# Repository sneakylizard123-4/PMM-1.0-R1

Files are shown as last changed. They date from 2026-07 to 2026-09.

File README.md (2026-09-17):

# PMM-1.0-R1 (Power Management Module)

A USB-C battery management module with charging, fuel gauging, and a switched 5V output.

## Custom Features

- BQ25895 2A buck charger with I2C control
- BQ27441-G1 fuel gauge
- TPS61089 boost converter for 5V output
- TPS22917 load
- TLV75733 3.3V LDO
- STM32C031C4T6 MCU
- 4-layer PCB, 50x30mm

## PCB Design

this board is designed to fit on a breadboard without much hassle
it is a 4-layer pcb with an inner ground layer

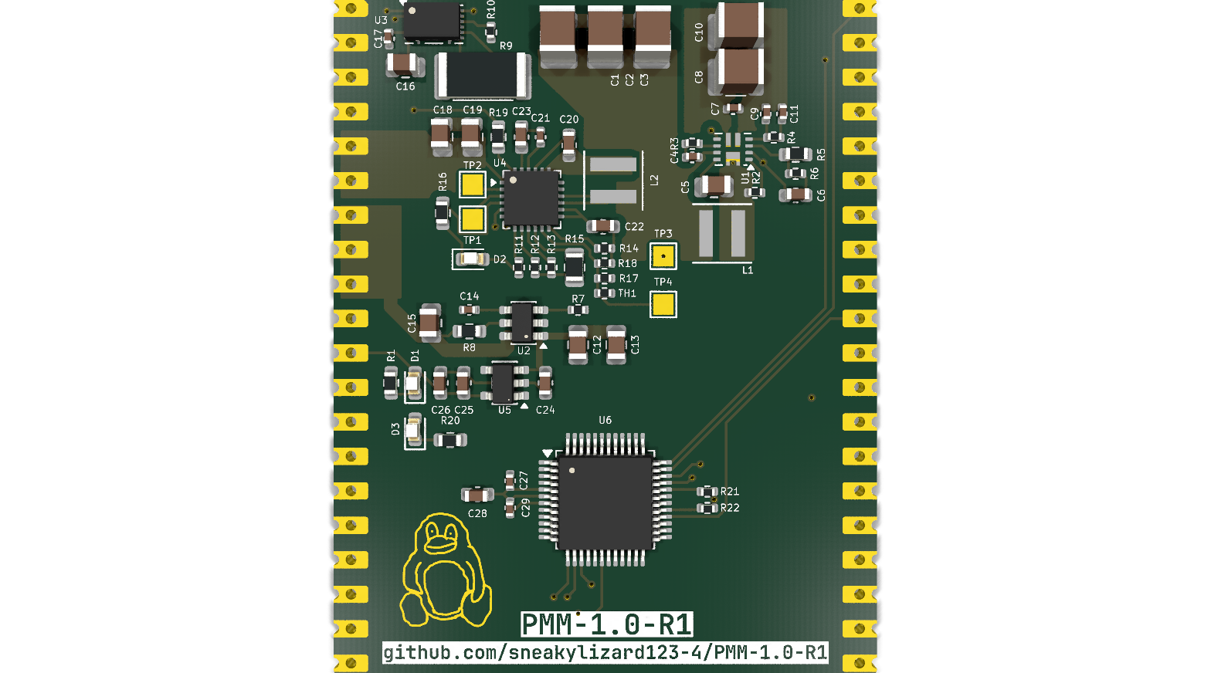
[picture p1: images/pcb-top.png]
PCB Top

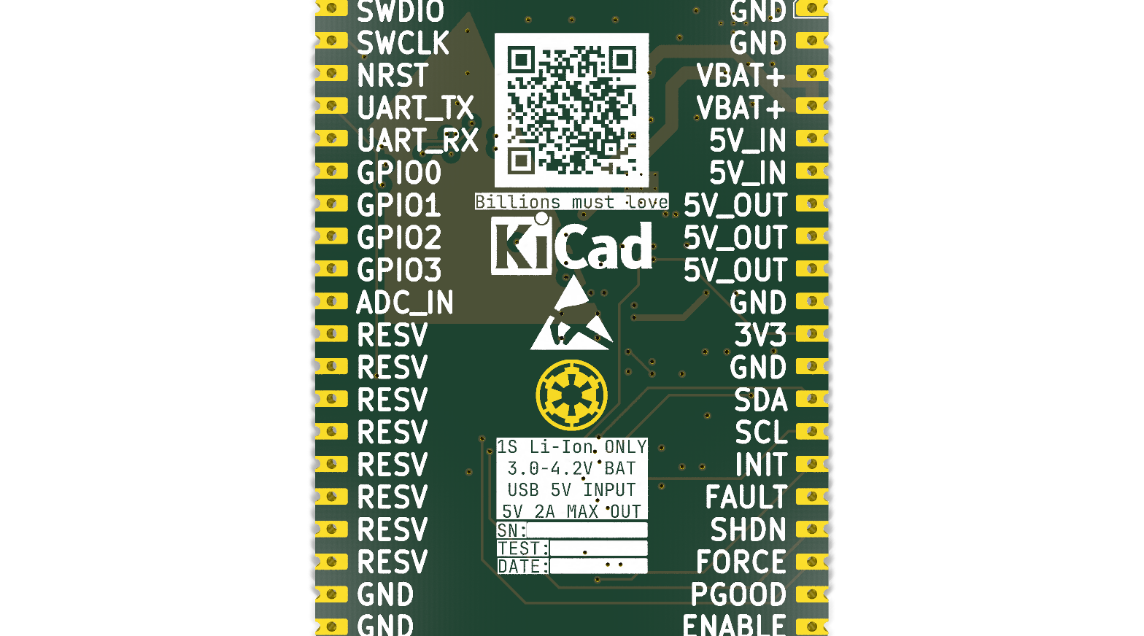
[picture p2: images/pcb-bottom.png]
PCB Bottom

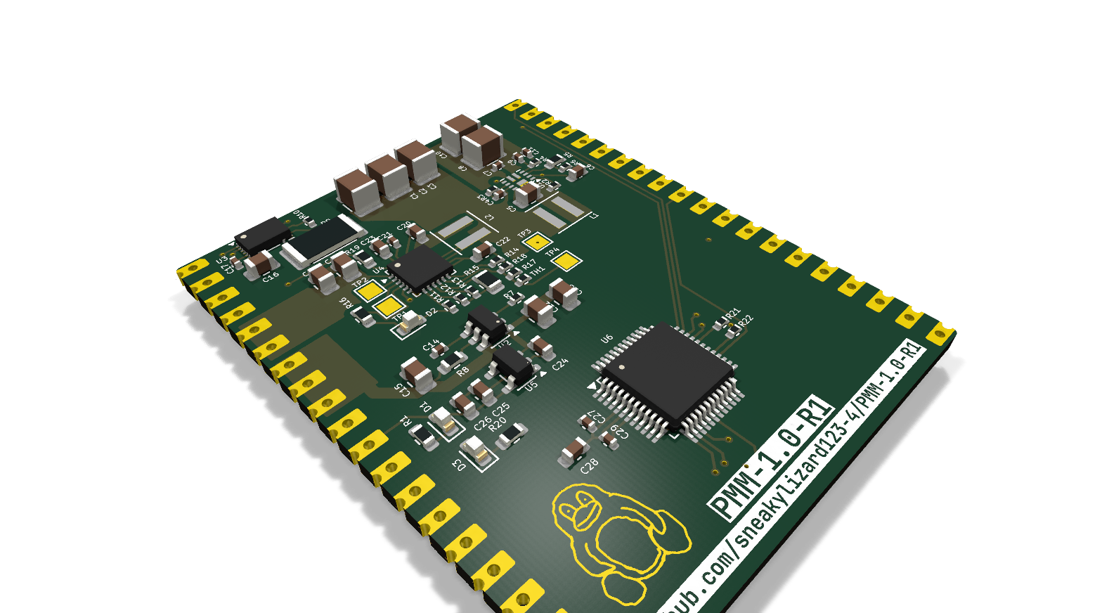
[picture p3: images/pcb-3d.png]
3D View


## Firmware

PlatformIO project using internal 48MHz oscillator (no crystal).

- I2C1 (PA9/PA10): BQ25895 charger at 0x6B, BQ27441 fuel gauge at 0x55
- USART2 (PA2/PA3): 115200 debug/status output
- ADC1 (PA8): VBUS monitoring
- GPIO: load switch (PA0), charger CE (PA4), LED (PA6), SHDN (PA11), FORCE_ON (PA12)

Flash with PlatformIO:

```
pio run -t upload
```

## BOM (Bill of Materials)

| Ref | Value | LCSC # | MPN | Manufacturer | Footprint | Qty | Unit $ | Ext $ | Link |
|-----|---|---|-----|---|---|-----|---|---|---|
| C1-C3,C8,C10 | 47uF 1210 16V X5R | C6783889 | 1210X476M160CT | Walsin | 1210 | 5 | 0.0900 | 0.4500 | [LCSC](https://www.lcsc.com/product-detail/C6783889.html) |
| C4,C7,C14,C27,C29 | 100nF 0402 25V X7R | C56392 | 0402B104K250NT | FH(Guangdong Fenghua) | 0402 | 5 | 0.0115 | 0.0575 | [LCSC](https://www.lcsc.com/product-detail/C56392.html) |
| C5 | 100nF 0805 50V X7R | C83055 | 0805B104K500CT | Walsin | 0805 | 1 | 0.0100 | 0.0100 | [LCSC](https://www.lcsc.com/product-detail/C83055.html) |
| C6,C22,C23,C28 | 10uF 0603 10V X5R | C19702 | CL10A106KP8NNNC | Samsung | 0603 | 4 | 0.0065 | 0.0260 | [LCSC](https://www.lcsc.com/product-detail/C19702.html) |
| C9 | 24pF 0402 C0G | C2242874 | C0402C240J4GACTU | KEMET | 0402 | 1 | 0.0100 | 0.0100 | [LCSC](https://www.lcsc.com/product-detail/C2242874.html) |
| C11 | 560pF 0402 C0G 50V | C3895255 | C0402C0G500-561FNP | Venkel | 0402 | 1 | 0.0313 | 0.0313 | [LCSC](https://www.lcsc.com/product-detail/C3895255.html) |
| C12,C19 | 100nF 0805 50V X7R | C83055 | 0805B104K500CT | Walsin | 0805 | 2 | 0.0100 | 0.0200 | [LCSC](https://www.lcsc.com/product-detail/C83055.html) |
| C13,C18 | 10uF 0805 10V X7R | C396720 | 0805B106K100CT | Walsin | 0805 | 2 | 0.0950 | 0.1900 | [LCSC](https://www.lcsc.com/product-detail/C396720.html) |
| C15 | 47uF 0805 10V X5R | C6119904 | CGA0805X5R476M100MT | HRE | 0805 | 1 | 0.1000 | 0.1000 | [LCSC](https://www.lcsc.com/product-detail/C6119904.html) |
| C16 | 1uF 0805 16V X7R | C2991444 | 0805B105K160CT-C | Walsin | 0805 | 1 | 0.0230 | 0.0230 | [LCSC](https://www.lcsc.com/product-detail/C2991444.html) |
| C17 | 0.47uF 0402 10V X5R | C47339 | CL05A474KP5NNNC | Samsung | 0402 | 1 | 0.0200 | 0.0200 | [LCSC](https://www.lcsc.com/product-detail/C47339.html) |
| C20 | 47nF 0603 25V X7R | C3881195 | C0603C473J3RAC7867 | KEMET | 0603 | 1 | 0.0100 | 0.0100 | [LCSC](https://www.lcsc.com/product-detail/C3881195.html) |
| C21 | 4.7uF 0402 6.3V X5R | C340648 | 0402X475M6R3CT | Walsin | 0402 | 1 | 0.0240 | 0.0240 | [LCSC](https://www.lcsc.com/product-detail/C340648.html) |
| C24,C25 | 1uF 0603 16V X7R | C106248 | CC0603KRX7R7BB105 | YAGEO | 0603 | 2 | 0.0310 | 0.0620 | [LCSC](https://www.lcsc.com/product-detail/C106248.html) |
| C26 | 100nF 0603 50V X7R | C14663 | CC0603KRX7R9BB104 | YAGEO | 0603 | 1 | 0.0100 | 0.0100 | [LCSC](https://www.lcsc.com/product-detail/C14663.html) |
| D1-D3 | LED 0603 emerald green | C7429914 | NCD0603G3 | NATIONSTAR | 0603 | 3 | 0.0080 | 0.0240 | [LCSC](https://www.lcsc.com/product-detail/C7429914.html) |
| L1 | 470nH shielded power inductor | C18221164 | XFL4015-471MEC | Coilcraft | SMD 4x4mm | 1 | 1.5000 | 1.5000 | [LCSC](https://www.lcsc.com/product-detail/C18221164.html) |
| L2 | 2.2uH shielded power inductor 8A | C122469 | XFL4020-222MEC | Coilcraft | SMD 4x4mm | 1 | 1.5000 | 1.5000 | [LCSC](https://www.lcsc.com/product-detail/C122469.html) |
| R1,R16,R19,R20 | 10k 0603 1% | C98220 | RC0603FR-0710KL | YAGEO | 0603 | 4 | 0.0100 | 0.0400 | [LCSC](https://www.lcsc.com/product-detail/C98220.html) |
| R2 | 309k 0402 1% | C171694 | RC0402FR-07309KL | YAGEO | 0402 | 1 | 0.0100 | 0.0100 | [LCSC](https://www.lcsc.com/product-detail/C171694.html) |
| R3 | 133k 0402 1% | C3015855 | SCR0402F133K | VO | 0402 | 1 | 0.0100 | 0.0100 | [LCSC](https://www.lcsc.com/product-detail/C3015855.html) |
| R4 | 28.7k 0402 1% | C185433 | RC0402FR-0728K7L | YAGEO | 0402 | 1 | 0.0100 | 0.0100 | [LCSC](https://www.lcsc.com/product-detail/C185433.html) |
| R5 | 240k 0603 1% | C137765 | RC0603FR-07240KL | YAGEO | 0603 | 1 | 0.0100 | 0.0100 | [LCSC](https://www.lcsc.com/product-detail/C137765.html) |
| R6 | 76.8k 0402 1% | C185396 | RC0402FR-0776K8L | YAGEO | 0402 | 1 | 0.0100 | 0.0100 | [LCSC](https://www.lcsc.com/product-detail/C185396.html) |
| R7 | 100k 0402 1% | C60491 | RC0402FR-07100KL | YAGEO | 0402 | 1 | 0.0060 | 0.0060 | [LCSC](https://www.lcsc.com/product-detail/C60491.html) |
| R8 | 100k 0603 1% | C14675 | RC0603FR-07100KL | YAGEO | 0603 | 1 | 0.0100 | 0.0100 | [LCSC](https://www.lcsc.com/product-detail/C14675.html) |
| R9 | 0.010 ohm 1% 2512 3W shunt | C520398 | LCSR2512FR010Q9L | RESI | 2512 | 1 | 0.1000 | 0.1000 | [LCSC](https://www.lcsc.com/product-detail/C520398.html) |
| R10-R14 | 10k 0402 1% | C60490 | RC0402FR-0710KL | YAGEO | 0402 | 5 | 0.0100 | 0.0500 | [LCSC](https://www.lcsc.com/product-detail/C60490.html) |
| R15 | 130 ohm 0805 1% | C273821 | RC0805FR-07130RL | YAGEO | 0805 | 1 | 0.0100 | 0.0100 | [LCSC](https://www.lcsc.com/product-detail/C273821.html) |
| R17 | 5.23k 0402 1% | C477746 | RC0402FR-075K23L | YAGEO | 0402 | 1 | 0.0100 | 0.0100 | [LCSC](https://www.lcsc.com/product-detail/C477746.html) |
| R18 | 30.1k 0402 1% | C138009 | RC0402FR-0730K1L | YAGEO | 0402 | 1 | 0.0100 | 0.0100 | [LCSC](https://www.lcsc.com/product-detail/C138009.html) |
| R21,R22 | 4.7k 0402 1% | C105871 | RC0402FR-074K7L | YAGEO | 0402 | 2 | 0.0100 | 0.0200 | [LCSC](https://www.lcsc.com/product-detail/C105871.html) |
| TH1 | 10k NTC thermistor 0402 | C77131 | NCP15XH103F03RC | muRata | 0402 | 1 | 0.0266 | 0.0266 | [LCSC](https://www.lcsc.com/product-detail/C77131.html) |
| U1 | TPS61089RNRR boost converter | C165129 | TPS61089RNRR | Texas Instruments | VQFN-11 | 1 | 0.5800 | 0.5800 | [LCSC](https://www.lcsc.com/product-detail/C165129.html) |
| U2 | TPS22917DBVR load switch | C2681320 | TPS22917DBVR | Texas Instruments | SOT-23-6 | 1 | 0.4600 | 0.4600 | [LCSC](https://www.lcsc.com/product-detail/C2681320.html) |
| U3 | BQ27441DRZR-G1B fuel gauge | C473374 | BQ27441DRZR-G1B | Texas Instruments | SON-12 | 1 | 2.7600 | 2.7600 | [LCSC](https://www.lcsc.com/product-detail/C473374.html) |
| U4 | BQ25895RTWR charger | C80200 | BQ25895RTWR | Texas Instruments | WQFN-24 | 1 | 2.1700 | 2.1700 | [LCSC](https://www.lcsc.com/product-detail/C80200.html) |
| U5 | TLV75733PDBVR 3.3V LDO | C485517 | TLV75733PDBVR | Texas Instruments | SOT-23-5 | 1 | 0.1950 | 0.1950 | [LCSC](https://www.lcsc.com/product-detail/C485517.html) |
| U6 | STM32C031C4T6 MCU | C5456207 | STM32C031C4T6 | STMicroelectronics | LQFP-48 | 1 | 1.6700 | 1.6700 | [LCSC](https://www.lcsc.com/product-detail/C5456207.html) |
| PCB | Bare PCB 50x30mm 4-layer | - | - | - | - | 1 | 2.5000 | 2.5000 | - |
| **Total** | - | - | - | - | - | **64** | - | **14.7354** | - |

Full BOM CSV: [BOM.csv](BOM.csv)

## Production

This board is designed for a standard 4-layer PCB fab:
- 4 layers
- HASL Lead Free
- 1.6mm board

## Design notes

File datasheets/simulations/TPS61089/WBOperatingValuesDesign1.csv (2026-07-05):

Name | Value | Category | Description
Phase Marg | 59.01 ° | System Information | Bode Plot Phase Margin
Cross Freq | 36.18 kHz | System Information | Bode plot crossover frequency
Low Freq Gain | 97.49 dB | System Information | Gain at 1Hz
Gain Marg | -13.31 dB | System Information | Bode Plot Gain Margin
Cin IRMS | 1.61 A | Capacitor | Input capacitor RMS ripple current
Cin Pd | 2.63 mW | Capacitor | Input capacitor power dissipation
Cout IRMS | 2.26 A | Capacitor | Output capacitor RMS ripple current
Cout Pd | 7.75 mW | Capacitor | Output capacitor power dissipation
Duty Cycle | 48.31% | System Information | Duty cycle
Efficiency | 93.7% | System Information | Steady state efficiency
Frequency | 496.71 kHz | System Information | Switching frequency
IC Tj | 53.04 °C | IC | IC junction temperature
ICThetaJA Effective | 39.2 °C/W | IC | Effective IC Junction-to-Ambient Thermal Resistance
L Ipp | 5.59 A | Inductor | Peak-to-peak inductor ripple current
L Pd | 71.05 mW | Inductor | Inductor power dissipation
IC Pd | 587.73 mW | IC | IC power dissipation
Pout | 10 W | System Information | Total output power
Iin Avg | 3.95 A | IC | Average input current
IC Ipk | 6.75 A | IC | Peak switch current in IC
Mode | BOOST CCM | System Information | PWM/PFM Mode
Vout p-p | 38.09 mV | System Information | Peak-to-peak output ripple voltage
Coutx Pd | 0 W | Capacitor | Output capacitor_x power loss
FootPrint | 144 mm² | System Information | Total Foot Print Area of BOM components
Vout Actual | 5 V | System Information | Vout Actual calculated based on selected voltage divider resistors
Vout Tolerance | 4.17% | System Information | Vout Tolerance based on IC Tolerance (no load) and voltage divider resistors if applicable
Vin | 2.7 V | System Information | Vin operating point
Iout | 2 A | System Information | Iout operating point
Cin Pd | 2.63 mW | Power | Input capacitor power dissipation
Cout Pd | 7.75 mW | Power | Output capacitor power dissipation
L Pd | 71.05 mW | Power | Inductor power dissipation
IC Pd | 587.73 mW | Power | IC power dissipation
Coutx Pd | 0 W | Power | Output capacitor_x power loss
Total BOM | $3.28 | System Information | Total BOM Cost
Total Pd | 669.29 mW | Power | Total Power Dissipation
BOM Count | 17 | System Information | Total Design BOM count

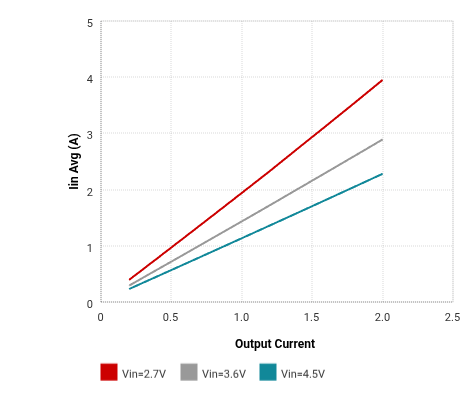
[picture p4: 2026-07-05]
datasheets/simulations/TPS61089/amCharts (8).png

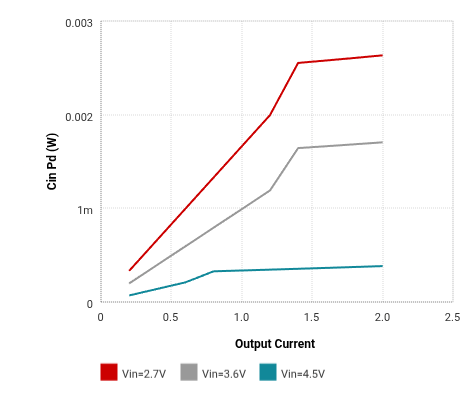
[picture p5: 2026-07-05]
datasheets/simulations/TPS61089/amCharts (5).png

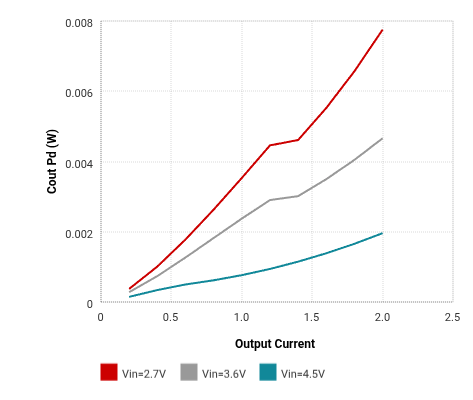
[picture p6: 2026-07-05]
datasheets/simulations/TPS61089/amCharts (12).png

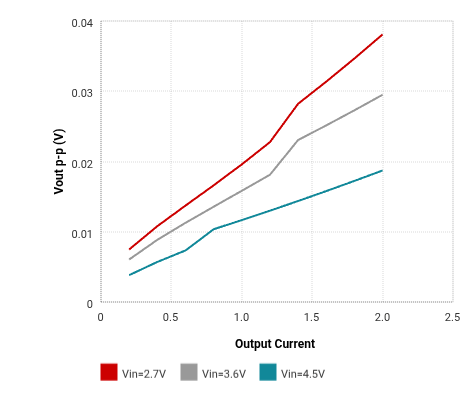
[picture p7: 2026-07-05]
datasheets/simulations/TPS61089/amCharts (1).png

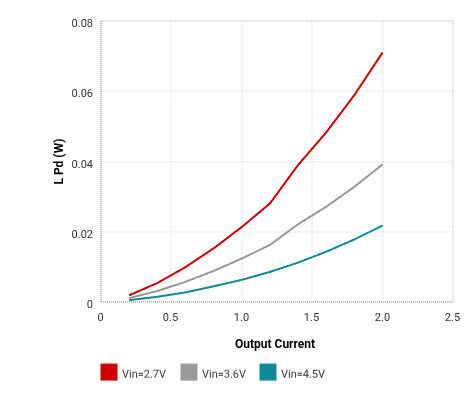
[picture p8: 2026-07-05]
datasheets/simulations/TPS61089/amCharts (15).png

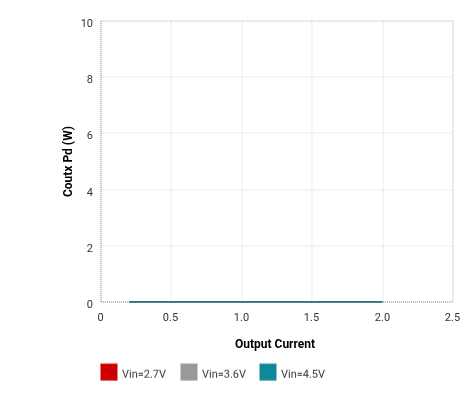
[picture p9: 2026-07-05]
datasheets/simulations/TPS61089/amCharts (7).png

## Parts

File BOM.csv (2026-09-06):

Ref | Value | Footprint | Qty | Manufacturer | MPN | LCSC Part | LCSC Link | Unit Price (USD) | Qty x Price
C1-C3,C8,C10 | 47uF 1210 16V X5R | Capacitor_SMD:C_1210_3225Metric | 5 | Walsin | 1210X476M160CT | C6783889 | https://www.lcsc.com/product-detail/C6783889.html | 0.0900 | 0.4500
C4,C7,C14,C27,C29 | 100nF 0402 25V X7R | Capacitor_SMD:C_0402_1005Metric | 5 | FH(Guangdong Fenghua) | 0402B104K250NT | C56392 | https://www.lcsc.com/product-detail/C56392.html | 0.0115 | 0.0575
C5 | 100nF 0805 50V X7R | Capacitor_SMD:C_0805_2012Metric | 1 | Walsin | 0805B104K500CT | C83055 | https://www.lcsc.com/product-detail/C83055.html | 0.0100 | 0.0100
C6,C22,C23,C28 | 10uF 0603 10V X5R | Capacitor_SMD:C_0603_1608Metric | 4 | Samsung | CL10A106KP8NNNC | C19702 | https://www.lcsc.com/product-detail/C19702.html | 0.0065 | 0.0260
C9 | 24pF 0402 C0G | Capacitor_SMD:C_0402_1005Metric | 1 | KEMET | C0402C240J4GACTU | C2242874 | https://www.lcsc.com/product-detail/C2242874.html | 0.0100 | 0.0100
C11 | 560pF 0402 C0G 50V | Capacitor_SMD:C_0402_1005Metric | 1 | Venkel | C0402C0G500-561FNP | C3895255 | https://www.lcsc.com/product-detail/C3895255.html | 0.0313 | 0.0313
C12,C19 | 100nF 0805 50V X7R | Capacitor_SMD:C_0805_2012Metric | 2 | Walsin | 0805B104K500CT | C83055 | https://www.lcsc.com/product-detail/C83055.html | 0.0100 | 0.0200
C13,C18 | 10uF 0805 10V X7R | Capacitor_SMD:C_0805_2012Metric | 2 | Walsin | 0805B106K100CT | C396720 | https://www.lcsc.com/product-detail/C396720.html | 0.0950 | 0.1900
C15 | 47uF 0805 10V X5R | Capacitor_SMD:C_0805_2012Metric | 1 | HRE | CGA0805X5R476M100MT | C6119904 | https://www.lcsc.com/product-detail/C6119904.html | 0.1000 | 0.1000
C16 | 1uF 0805 16V X7R | Capacitor_SMD:C_0805_2012Metric | 1 | Walsin | 0805B105K160CT-C | C2991444 | https://www.lcsc.com/product-detail/C2991444.html | 0.0230 | 0.0230
C17 | 0.47uF 0402 10V X5R | Capacitor_SMD:C_0402_1005Metric | 1 | Samsung | CL05A474KP5NNNC | C47339 | https://www.lcsc.com/product-detail/C47339.html | 0.0200 | 0.0200
C20 | 47nF 0603 25V X7R | Capacitor_SMD:C_0603_1608Metric | 1 | KEMET | C0603C473J3RAC7867 | C3881195 | https://www.lcsc.com/product-detail/C3881195.html | 0.0100 | 0.0100
C21 | 4.7uF 0402 6.3V X5R | Capacitor_SMD:C_0402_1005Metric | 1 | Walsin | 0402X475M6R3CT | C340648 | https://www.lcsc.com/product-detail/C340648.html | 0.0240 | 0.0240
C24,C25 | 1uF 0603 16V X7R | Capacitor_SMD:C_0603_1608Metric | 2 | YAGEO | CC0603KRX7R7BB105 | C106248 | https://www.lcsc.com/product-detail/C106248.html | 0.0310 | 0.0620
C26 | 100nF 0603 50V X7R | Capacitor_SMD:C_0603_1608Metric | 1 | YAGEO | CC0603KRX7R9BB104 | C14663 | https://www.lcsc.com/product-detail/C14663.html | 0.0100 | 0.0100
D1-D3 | LED 0603 emerald green | LED_SMD:LED_0603_1608Metric | 3 | NATIONSTAR | NCD0603G3 | C7429914 | https://www.lcsc.com/product-detail/C7429914.html | 0.0080 | 0.0240
L1 | 470nH shielded power inductor | Inductor_SMD:L_Coilcraft_XxL4020 | 1 | Coilcraft | XFL4015-471MEC | C18221164 | https://www.lcsc.com/product-detail/C18221164.html | 1.5000 | 1.5000
L2 | 2.2uH shielded power inductor 8A | Inductor_SMD:L_Coilcraft_XxL4020 | 1 | Coilcraft | XFL4020-222MEC | C122469 | https://www.lcsc.com/product-detail/C122469.html | 1.5000 | 1.5000
R1,R16,R19,R20 | 10k 0603 1% | Resistor_SMD:R_0603_1608Metric | 4 | YAGEO | RC0603FR-0710KL | C98220 | https://www.lcsc.com/product-detail/C98220.html | 0.0100 | 0.0400
R2 | 309k 0402 1% | Resistor_SMD:R_0402_1005Metric | 1 | YAGEO | RC0402FR-07309KL | C171694 | https://www.lcsc.com/product-detail/C171694.html | 0.0100 | 0.0100
R3 | 133k 0402 1% | Resistor_SMD:R_0402_1005Metric | 1 | VO | SCR0402F133K | C3015855 | https://www.lcsc.com/product-detail/C3015855.html | 0.0100 | 0.0100
R4 | 28.7k 0402 1% | Resistor_SMD:R_0402_1005Metric | 1 | YAGEO | RC0402FR-0728K7L | C185433 | https://www.lcsc.com/product-detail/C185433.html | 0.0100 | 0.0100
R5 | 240k 0603 1% | Resistor_SMD:R_0603_1608Metric | 1 | YAGEO | RC0603FR-07240KL | C137765 | https://www.lcsc.com/product-detail/C137765.html | 0.0100 | 0.0100
R6 | 76.8k 0402 1% | Resistor_SMD:R_0402_1005Metric | 1 | YAGEO | RC0402FR-0776K8L | C185396 | https://www.lcsc.com/product-detail/C185396.html | 0.0100 | 0.0100
R7 | 100k 0402 1% | Resistor_SMD:R_0402_1005Metric | 1 | YAGEO | RC0402FR-07100KL | C60491 | https://www.lcsc.com/product-detail/C60491.html | 0.0060 | 0.0060
R8 | 100k 0603 1% | Resistor_SMD:R_0603_1608Metric | 1 | YAGEO | RC0603FR-07100KL | C14675 | https://www.lcsc.com/product-detail/C14675.html | 0.0100 | 0.0100
R9 | 0.010 ohm 1% 2512 3W shunt | Resistor_SMD:R_2512_6332Metric | 1 | RESI | LCSR2512FR010Q9L | C520398 | https://www.lcsc.com/product-detail/C520398.html | 0.1000 | 0.1000
R10-R14 | 10k 0402 1% | Resistor_SMD:R_0402_1005Metric | 5 | YAGEO | RC0402FR-0710KL | C60490 | https://www.lcsc.com/product-detail/C60490.html | 0.0100 | 0.0500
R15 | 130 ohm 0805 1% | Resistor_SMD:R_0805_2012Metric | 1 | YAGEO | RC0805FR-07130RL | C273821 | https://www.lcsc.com/product-detail/C273821.html | 0.0100 | 0.0100
R17 | 5.23k 0402 1% | Resistor_SMD:R_0402_1005Metric | 1 | YAGEO | RC0402FR-075K23L | C477746 | https://www.lcsc.com/product-detail/C477746.html | 0.0100 | 0.0100
R18 | 30.1k 0402 1% | Resistor_SMD:R_0402_1005Metric | 1 | YAGEO | RC0402FR-0730K1L | C138009 | https://www.lcsc.com/product-detail/C138009.html | 0.0100 | 0.0100
R21,R22 | 4.7k 0402 1% | Resistor_SMD:R_0402_1005Metric | 2 | YAGEO | RC0402FR-074K7L | C105871 | https://www.lcsc.com/product-detail/C105871.html | 0.0100 | 0.0200
TH1 | 10k NTC thermistor 0402 | Resistor_SMD:R_0402_1005Metric | 1 | muRata | NCP15XH103F03RC | C77131 | https://www.lcsc.com/product-detail/C77131.html | 0.0266 | 0.0266
U1 | TPS61089RNRR boost converter | Package_DFN_QFN:Texas_VQFN-RNR0011A-11 | 1 | Texas Instruments | TPS61089RNRR | C165129 | https://www.lcsc.com/product-detail/C165129.html | 0.5800 | 0.5800
U2 | TPS22917DBVR load switch | Package_TO_SOT_SMD:SOT-23-6 | 1 | Texas Instruments | TPS22917DBVR | C2681320 | https://www.lcsc.com/product-detail/C2681320.html | 0.4600 | 0.4600
U3 | BQ27441DRZR-G1B fuel gauge | Package_SON:Texas_S-PDSO-N12 | 1 | Texas Instruments | BQ27441DRZR-G1B | C473374 | https://www.lcsc.com/product-detail/C473374.html | 2.7600 | 2.7600
U4 | BQ25895RTWR charger | Package_DFN_QFN:Texas_RTW_WQFN-24-1EP_4x4mm_P0.5mm_EP2.7x2.7mm_ThermalVias | 1 | Texas Instruments | BQ25895RTWR | C80200 | https://www.lcsc.com/product-detail/C80200.html | 2.1700 | 2.1700
U5 | TLV75733PDBVR 3.3V LDO | Package_TO_SOT_SMD:SOT-23-5 | 1 | Texas Instruments | TLV75733PDBVR | C485517 | https://www.lcsc.com/product-detail/C485517.html | 0.1950 | 0.1950
U6 | STM32C031C4T6 MCU | Package_QFP:LQFP-48_7x7mm_P0.5mm | 1 | STMicroelectronics | STM32C031C4T6 | C5456207 | https://www.lcsc.com/product-detail/C5456207.html | 1.6700 | 1.6700
 |  |  |  |  |  |  | TOTAL PER BOARD | 12.2354

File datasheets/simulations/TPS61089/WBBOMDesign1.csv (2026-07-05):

Part | Manufacturer | Part Number | Quantity | Price ($) | Footprint (mm²) | Description
Cbst | AVX | 08053C104KAT2A | 1 | 0.01 | 6.75 | Cap: 100 nF Total Derated Cap: 100 nF VDC: 25 V ESR: 280 mΩ Package: 0805
Ccomp | MuRata | GRM1555C1H561JA01J | 1 | 0.01 | 3 | Cap: 560 pF Total Derated Cap: 560 pF VDC: 50 V ESR: 0 Ω Package: 0402
Ccomp2 | Yageo | CC0402JRNPO9BN240 | 1 | 0.01 | 3 | Cap: 24 pF Total Derated Cap: 24 pF VDC: 50 V ESR: 0 Ω Package: 0402
Cin | MuRata | GRM32ER61C476KE15L | 3 | 0.17 | 14.7 | Cap: 47 µF Total Derated Cap: 95 µF VDC: 16 V ESR: 3.04 mΩ Package: 1210
Cin2 | MuRata | GRM155R71C104KA88D | 1 | 0.01 | 3 | Cap: 100 nF Total Derated Cap: 94 nF VDC: 16 V ESR: 1 mΩ Package: 0402
Cout | MuRata | GRM32ER61C476KE15L | 2 | 0.17 | 14.7 | Cap: 47 µF Total Derated Cap: 63 µF VDC: 16 V ESR: 3.04 mΩ Package: 1210
Cvcc | TDK | C1608X5R1A106K080AC | 1 | 0.06327 | 4.68 | Cap: 10 µF Total Derated Cap: 2.4 µF VDC: 10 V ESR: 4.62 mΩ Package: 0603
L1 | Coilcraft | XGL4030-471MEC | 1 | 1.26 | 25 | L: 470 nH DCR: 3.9 mΩ IDC: 14.2 A
Rcomp | Yageo | RC0201FR-0728K7L | 1 | 0.01 | 2.08 | Resistance: 28.7 kΩ Tolerance: 1.0% Power: 50 mW
Rfbb | Vishay-Dale | CRCW040276K8FKED | 1 | 0.01 | 3 | Resistance: 76.8 kΩ Tolerance: 1.0% Power: 63 mW
Rfbt | Yageo | RC0603FR-07240KL | 1 | 0.01 | 4.68 | Resistance: 240 kΩ Tolerance: 1.0% Power: 100 mW
Rlim | Yageo | RC0201FR-07133KL | 1 | 0.01 | 2.08 | Resistance: 133 kΩ Tolerance: 1.0% Power: 50 mW
Rt | Vishay-Dale | CRCW0402309KFKED | 1 | 0.01 | 3 | Resistance: 309 kΩ Tolerance: 1.0% Power: 63 mW
U1 | Texas Instruments | TPS61089RNRR | 1 | 1.012 | 10.5

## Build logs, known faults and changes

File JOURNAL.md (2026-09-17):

---
title: PMM-1.0-R1
author: sneakylizard123-4
description: "Power Management Module - USB-C charging, battery fuel gauge, 5V boost output"
created_at: 2026-07-05
---

# July 5: first commit

started pmm project
needed an easy power solution

it has a dedicated fuel gauge and boost converter

used ti web bench to make sim
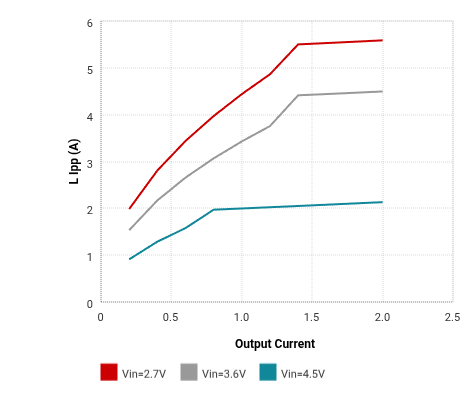
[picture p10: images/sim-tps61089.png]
sim


**Total Time Spent: 4 hours**

# July 7: 3.3V regulator

added a 3.3v regulator
used tlv75733 ldo
it doesnt need to be too complex

tlv75733

**Total Time Spent: 2 hours**

# July 9: sub-sheets and regulator fixes

split into subsheets for more clean schematic
each sheet has its own dedicated thing
fixed the 3.3v regulator.
root-sch

**Total Time Spent: 3 hours**

# July 13: finished schematics

connected all the subsheets together
wired up the stm32

drew a custom pmm schematic and footprint to make wiring easier, it has castellated edges like a pi pico
stm32

**Total Time Spent: 5 hours**

# July 14: PCB routing

started routing pcb, power is hard
added tlv757 datasheet
pcb

**Total Time Spent: 6 hours**

# July 16: finished PCB

finished routing pcb, high power areas were tough
routed the remaining charger traces.
pcb

**Total Time Spent: 5 hours**

# July 17: silkscreen and cleanup

silkscreen art: empire logo and penguin.
cleaned up parts library
pcb-bottom

**Total Time Spent: 3 hours**

# July 21: firmware

using platformio for firmware
using internal oscillator
using i2c and usart
wrote firmware in firmware/
still have lots of headroom in flash and ram
bq25895

**Total Time Spent: 4 hours**

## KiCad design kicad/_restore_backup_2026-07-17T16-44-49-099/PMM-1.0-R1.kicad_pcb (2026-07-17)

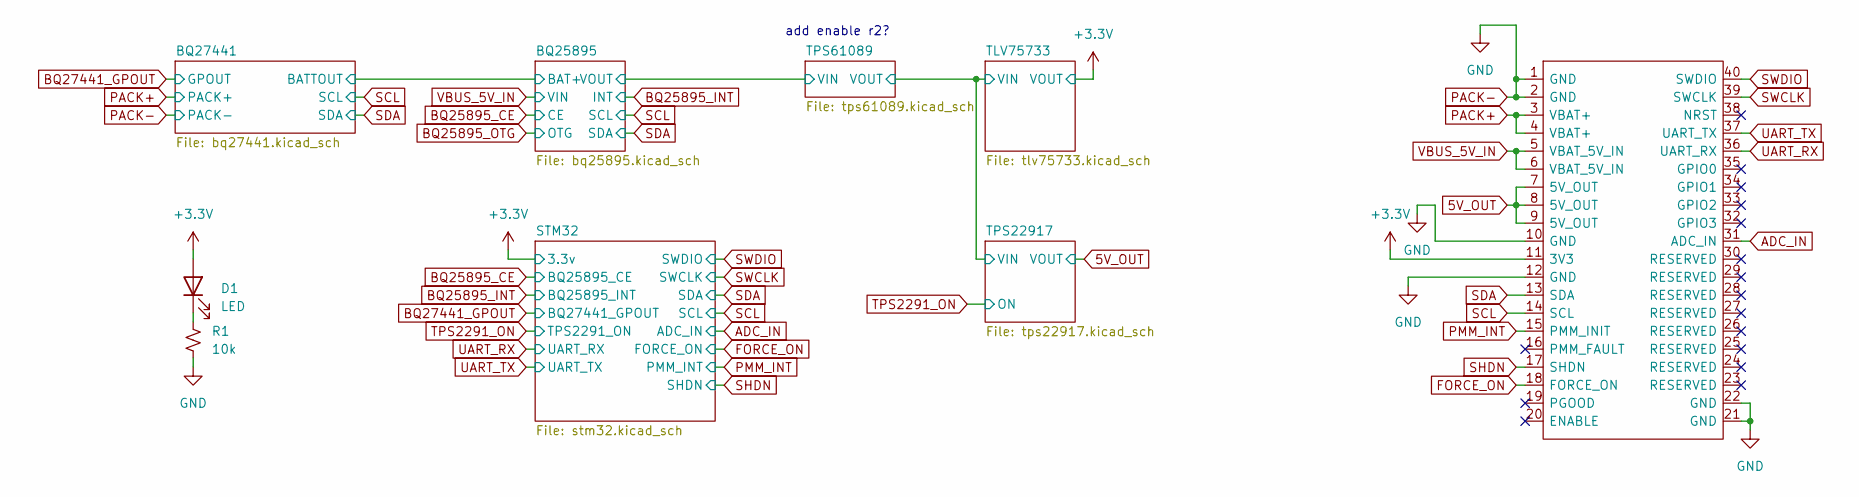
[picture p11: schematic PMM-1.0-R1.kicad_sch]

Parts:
A1: PMM
D1: LED; LED_0603_1608Metric
R1: 10k; R_0603_1608Metric

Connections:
5V_OUT: A1.7 (5V_OUT), A1.8 (5V_OUT), A1.9 (5V_OUT); also elsewhere on the board
+3.3V: A1.11 (3V3), D1.2 (A); also elsewhere on the board
ADC_IN: A1.31 (ADC_IN); also elsewhere on the board
FORCE_ON: A1.18 (FORCE_ON); also elsewhere on the board
unnamed: D1.1 (K), R1.1
PACK+: A1.3 (VBAT+), A1.4 (VBAT+); also elsewhere on the board
PACK-: A1.1 (GND), A1.2 (GND), A1.10 (GND), A1.12 (GND), A1.21 (GND), A1.22 (GND), R1.2; also elsewhere on the board
PMM_INT: A1.15 (PMM_INIT); also elsewhere on the board
SCL: A1.14 (SCL); also elsewhere on the board
SDA: A1.13 (SDA); also elsewhere on the board
SHDN: A1.17 (SHDN); also elsewhere on the board
SWCLK: A1.39 (SWCLK); also elsewhere on the board
SWDIO: A1.40 (SWDIO); also elsewhere on the board
UART_RX: A1.36 (UART_RX); also elsewhere on the board
UART_TX: A1.37 (UART_TX); also elsewhere on the board
VBUS_5V_IN: A1.5 (VBAT_5V_IN), A1.6 (VBAT_5V_IN); also elsewhere on the board

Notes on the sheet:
add enable r2?

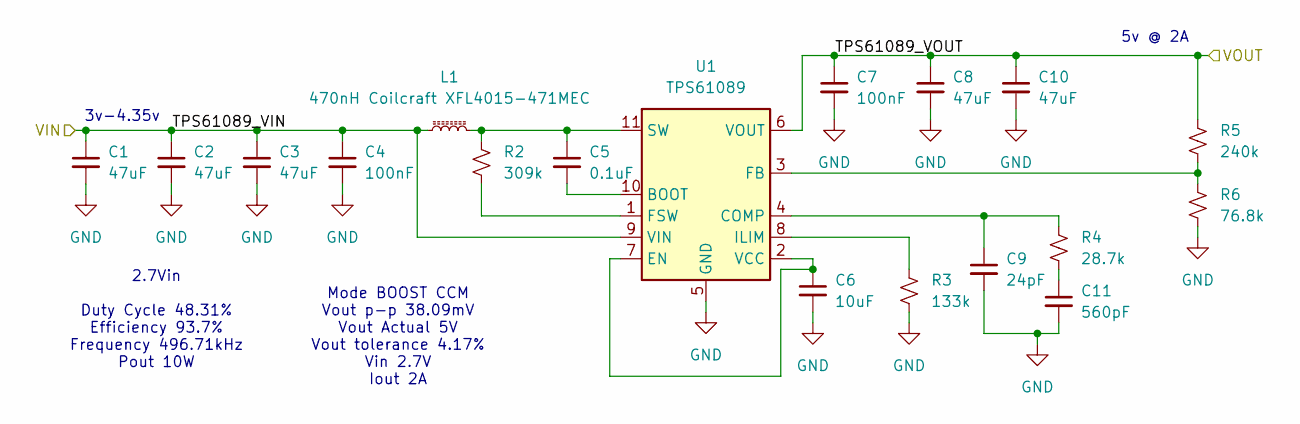
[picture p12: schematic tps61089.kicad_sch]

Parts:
C1, C2, C3, C8, C10: 47uF; C_1210_3225Metric
C4, C7: 100nF; C_0402_1005Metric
C5: 0.1uF; C_0805_2012Metric
C6: 10uF; C_0603_1608Metric
C9: 24pF; C_0402_1005Metric
C11: 560pF; C_0402_1005Metric
L1: 470nH Coilcraft XFL4015-471MEC; L_Coilcraft_XxL4020
R2: 309k; R_0402_1005Metric
R3: 133k; R_0402_1005Metric
R4: 28.7k; R_0402_1005Metric
R5: 240k; R_0603_1608Metric
R6: 76.8k; R_0402_1005Metric
U1: TPS61089; Texas_VQFN-RNR0011A-11

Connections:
/BQ25895/BQ25895_VOUT: C1.1, C2.1, C3.1, C4.1, L1.1, U1.9 (VIN); also elsewhere on the board
/TPS61089/TPS61089_VOUT: C7.1, C8.1, C10.1, R5.1, U1.6 (VOUT); also elsewhere on the board
unnamed: C11.1, R4.2
unnamed: C5.2, U1.10 (BOOT)
unnamed: C9.1, R4.1, U1.4 (COMP)
unnamed: C6.1, U1.2 (VCC), U1.7 (EN)
unnamed: R5.2, R6.1, U1.3 (FB)
unnamed: R2.2, U1.1 (FSW)
unnamed: R3.1, U1.8 (ILIM)
unnamed: C5.1, L1.2, R2.1, U1.11 (SW)
PACK-: C1.2, C2.2, C3.2, C4.2, C6.2, C7.2, C8.2, C9.2, C10.2, C11.2, R3.2, R6.2, U1.5 (GND); also elsewhere on the board

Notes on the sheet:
Mode BOOST CCM Vout p-p 38.09mV Vout Actual 5V Vout tolerance 4.17% Vin 2.7V Iout 2A
3v-4.35v
5v @ 2A
2.7Vin Duty Cycle 48.31% Efficiency 93.7% Frequency 496.71kHz Pout 10W

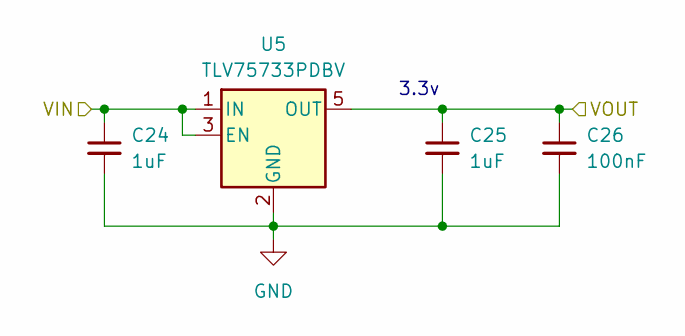
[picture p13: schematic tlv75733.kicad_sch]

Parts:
C24, C25: 1uF; C_0603_1608Metric
C26: 100nF; C_0603_1608Metric
U5: TLV75733PDBV; SOT-23-5

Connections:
+3.3V: C25.1, C26.1, U5.5 (OUT); also elsewhere on the board
/TPS61089/TPS61089_VOUT: C24.1, U5.1 (IN), U5.3 (EN); also elsewhere on the board
PACK-: C24.2, C25.2, C26.2, U5.2 (GND); also elsewhere on the board

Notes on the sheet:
3.3v

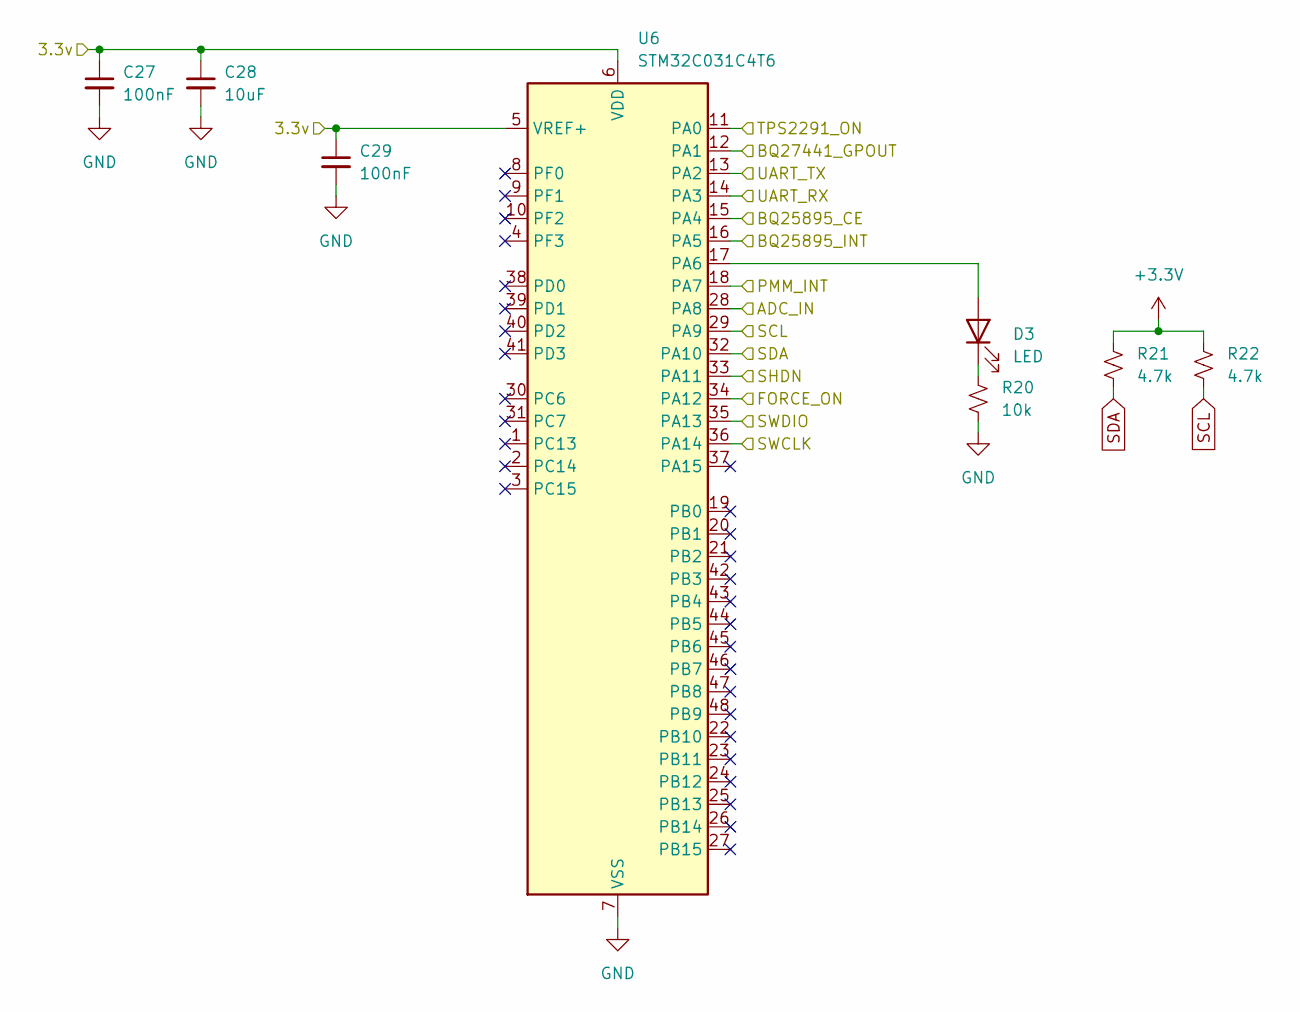
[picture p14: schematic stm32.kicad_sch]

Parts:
C27, C29: 100nF; C_0402_1005Metric
C28: 10uF; C_0603_1608Metric
D3: LED; LED_0603_1608Metric
R20: 10k; R_0603_1608Metric
R21, R22: 4.7k; R_0402_1005Metric
U6: STM32C031C4T6; LQFP-48_7x7mm_P0.5mm

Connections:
+3.3V: C27.1, C28.1, C29.1, R21.1, R22.1, U6.5 (VREF+), U6.6 (VDD); also elsewhere on the board
ADC_IN: U6.28 (PA8); also elsewhere on the board
BQ25895_CE: U6.15 (PA4); also elsewhere on the board
BQ25895_INT: U6.16 (PA5); also elsewhere on the board
BQ27441_GPOUT: U6.12 (PA1); also elsewhere on the board
FORCE_ON: U6.34 (PA12); also elsewhere on the board
unnamed: D3.2 (A), U6.17 (PA6)
unnamed: D3.1 (K), R20.1
PACK-: C27.2, C28.2, C29.2, R20.2, U6.7 (VSS); also elsewhere on the board
PMM_INT: U6.18 (PA7); also elsewhere on the board
SCL: R22.2, U6.29 (PA9); also elsewhere on the board
SDA: R21.2, U6.32 (PA10); also elsewhere on the board
SHDN: U6.33 (PA11); also elsewhere on the board
SWCLK: U6.36 (PA14); also elsewhere on the board
SWDIO: U6.35 (PA13); also elsewhere on the board
TPS2291_ON: U6.11 (PA0); also elsewhere on the board
UART_RX: U6.14 (PA3); also elsewhere on the board
UART_TX: U6.13 (PA2); also elsewhere on the board

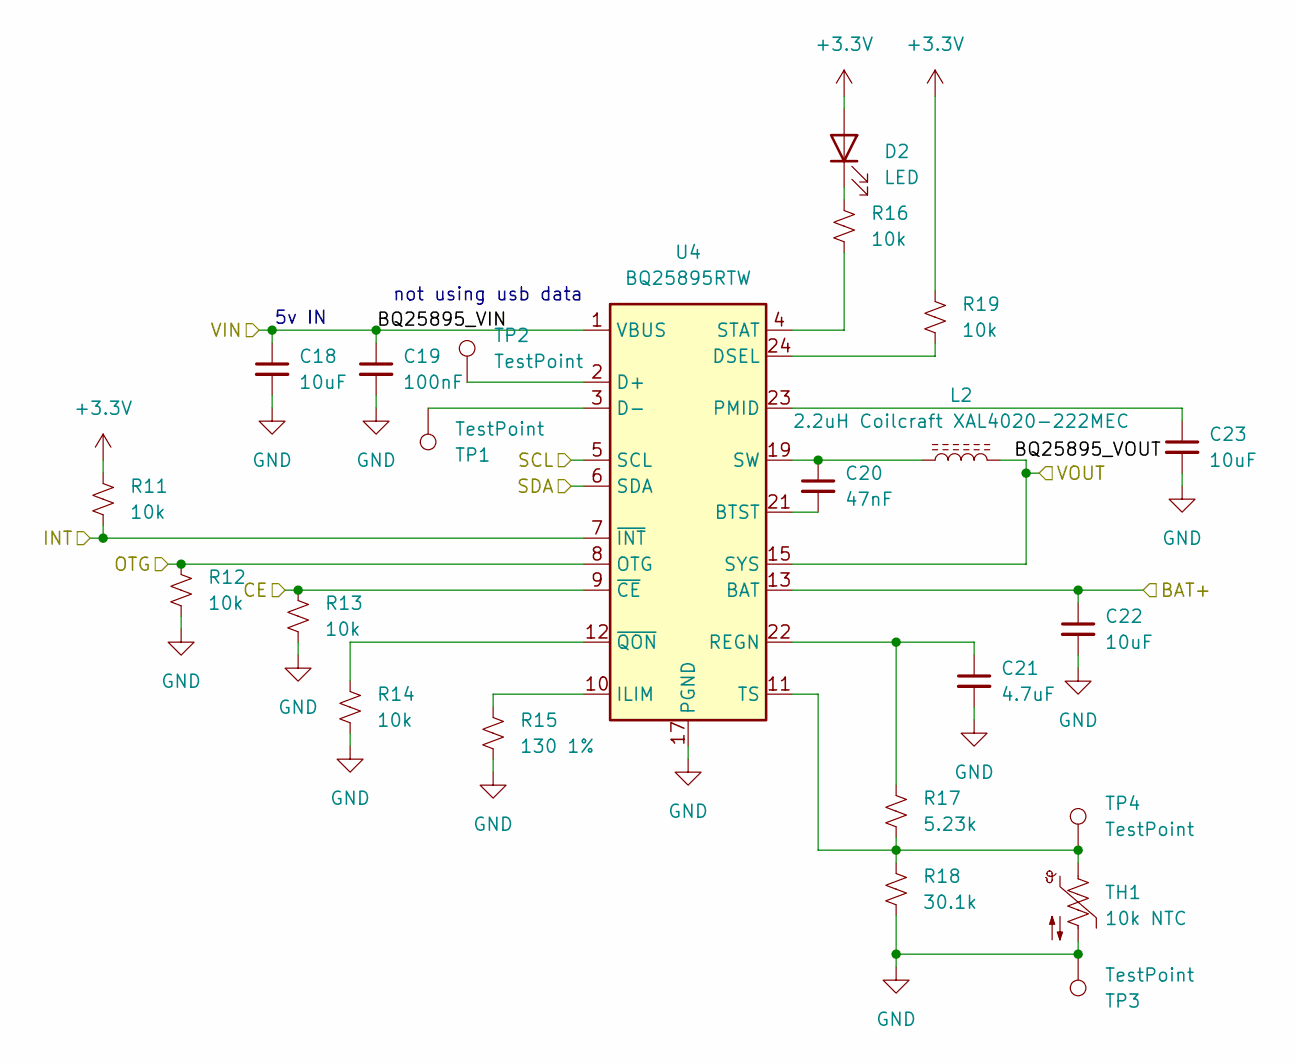
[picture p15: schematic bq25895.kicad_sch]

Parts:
C18: 10uF; C_0805_2012Metric
C19: 100nF; C_0805_2012Metric
C20: 47nF; C_0603_1608Metric
C21: 4.7uF; C_0402_1005Metric
C22, C23: 10uF; C_0603_1608Metric
D2: LED; LED_0603_1608Metric
L2: 2.2uH Coilcraft XAL4020-222MEC; L_Coilcraft_XxL4020
R11, R12, R13, R14: 10k; R_0402_1005Metric
R15: 130 1%; R_0805_2012Metric
R16, R19: 10k; R_0603_1608Metric
R17: 5.23k; R_0402_1005Metric
R18: 30.1k; R_0402_1005Metric
TH1: 10k NTC; R_0402_1005Metric
TP1, TP2, TP3, TP4: TestPoint; TestPoint_Pad_1.5x1.5mm
U4: BQ25895RTW; Texas_RTW_WQFN-24-1EP_4x4mm_P0.5mm_EP2.7x2.7mm_ThermalVias

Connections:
+3.3V: D2.2 (A), R11.1, R19.1; also elsewhere on the board
/BQ25895/BAT+: C22.1, U4.13 (BAT), U4.14 (BAT); also elsewhere on the board
/BQ25895/BQ25895_VOUT: L2.2, U4.15 (SYS), U4.16 (SYS); also elsewhere on the board
BQ25895_CE: R13.1, U4.9 (~CE); also elsewhere on the board
BQ25895_INT: R11.2, U4.7 (~INT); also elsewhere on the board
BQ25895_OTG: R12.1, U4.8 (OTG)
unnamed: C20.1, L2.1, U4.19 (SW), U4.20 (SW)
unnamed: D2.1 (K), R16.1
unnamed: C20.2, U4.21 (BTST)
unnamed: TP2.1 (1_1), U4.2 (D+)
unnamed: TP1.1 (1_1), U4.3 (D-)
unnamed: R19.2, U4.24 (DSEL)
unnamed: R15.1, U4.10 (ILIM)
unnamed: C23.1, U4.23 (PMID)
unnamed: C21.1, R17.1, U4.22 (REGN)
unnamed: R16.2, U4.4 (STAT)
unnamed: R17.2, R18.1, TH1.1, TP4.1 (1_1), U4.11 (TS)
unnamed: R14.1, U4.12 (~QON)
PACK-: C18.2, C19.2, C21.2, C22.2, C23.2, R12.2, R13.2, R14.2, R15.2, R18.2, TH1.2, TP3.1 (1_1), U4.17 (PGND), U4.18 (PGND), U4.25 (PGND); also elsewhere on the board
SCL: U4.5 (SCL); also elsewhere on the board
SDA: U4.6 (SDA); also elsewhere on the board
VBUS_5V_IN: C18.1, C19.1, U4.1 (VBUS); also elsewhere on the board

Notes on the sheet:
not using usb data
5v IN

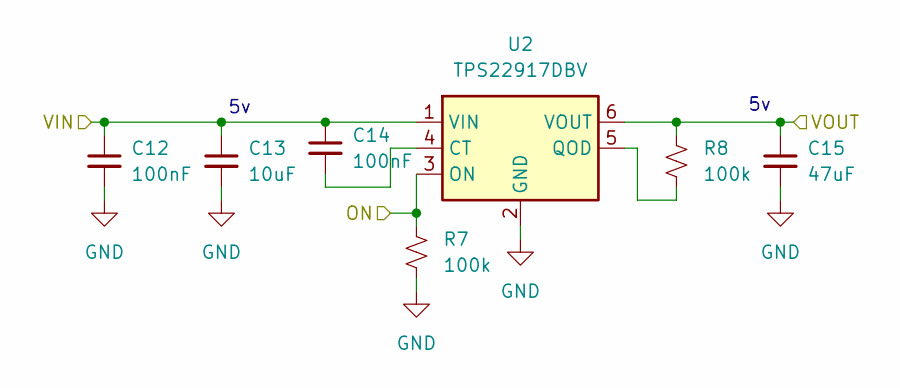
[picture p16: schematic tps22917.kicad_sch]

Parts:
C12: 100nF; C_0805_2012Metric
C13: 10uF; C_0805_2012Metric
C14: 100nF; C_0402_1005Metric
C15: 47uF; C_0805_2012Metric
R7: 100k; R_0402_1005Metric
R8: 100k; R_0603_1608Metric
U2: TPS22917DBV; SOT-23-6

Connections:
5V_OUT: C15.1, R8.1, U2.6 (VOUT); also elsewhere on the board
/TPS61089/TPS61089_VOUT: C12.1, C13.1, C14.1, U2.1 (VIN); also elsewhere on the board
unnamed: C14.2, U2.4 (CT)
unnamed: R8.2, U2.5 (QOD)
PACK-: C12.2, C13.2, C15.2, R7.2, U2.2 (GND); also elsewhere on the board
TPS2291_ON: R7.1, U2.3 (ON); also elsewhere on the board

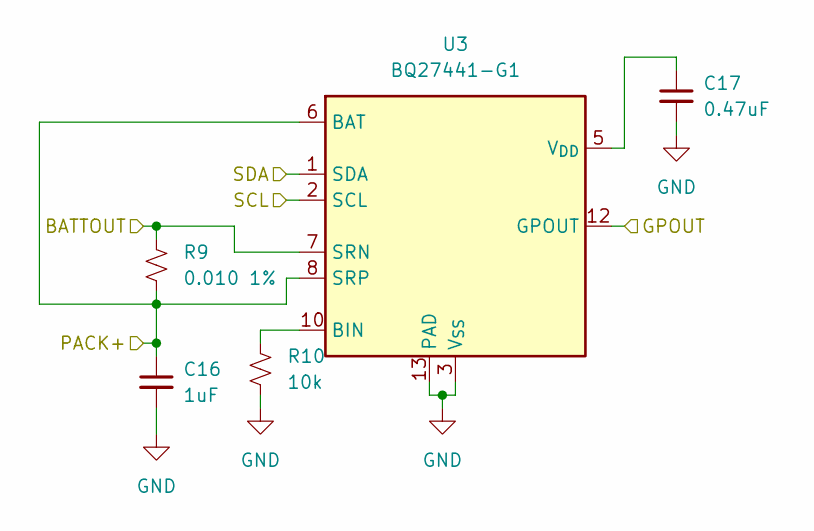
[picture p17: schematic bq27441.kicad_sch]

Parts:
C16: 1uF; C_0805_2012Metric
C17: 0.47uF; C_0402_1005Metric
R9: 0.010 1%; R_2512_6332Metric
R10: 10k; R_0402_1005Metric
U3: BQ27441-G1; Texas_S-PDSO-N12

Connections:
/BQ25895/BAT+: R9.1, U3.7 (SRN); also elsewhere on the board
BQ27441_GPOUT: U3.12 (GPOUT); also elsewhere on the board
unnamed: R10.1, U3.10 (BIN)
unnamed: C17.1, U3.5 (V_{DD})
PACK+: C16.1, R9.2, U3.6 (BAT), U3.8 (SRP); also elsewhere on the board
PACK-: C16.2, C17.2, R10.2, U3.3 (V_{SS}), U3.13 (PAD); also elsewhere on the board
SCL: U3.2 (SCL); also elsewhere on the board
SDA: U3.1 (SDA); also elsewhere on the board

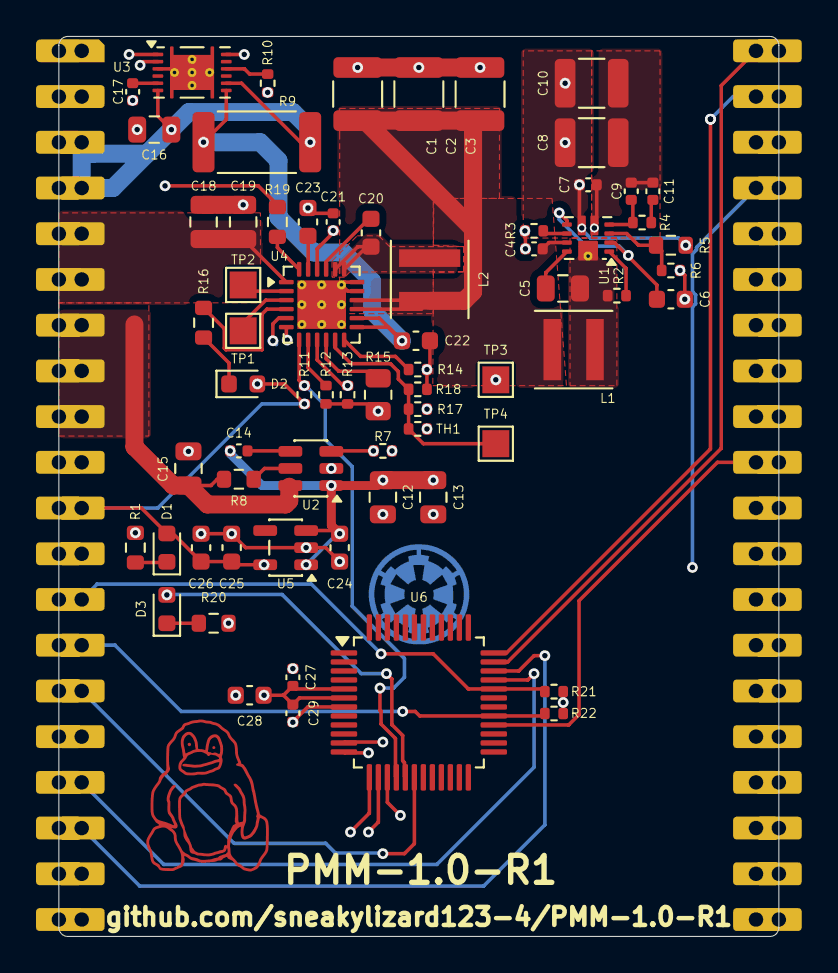
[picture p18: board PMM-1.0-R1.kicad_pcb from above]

Board: 4 copper layers, 40.0 x 50.0 mm, 68 parts (0 on the bottom side), 50 nets.

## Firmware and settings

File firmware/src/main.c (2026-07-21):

/**
 * @file main.c
 * @brief PMM-1.0-R1 application entry point.
 *
 * Initialises the PMM system, then runs the main poll loop forever.
 * LED blinks at 2 Hz; UART prints status every second.
 */

#include "pmm.h"
#include "pmm_config.h"

int main(void)
{
    pmm_init();

    /* Main loop */
    for (;;) {
        pmm_poll();
    }
}

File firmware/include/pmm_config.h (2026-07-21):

/**
 * @file pmm_config.h
 * @brief PMM-1.0-R1 hardware configuration and pin definitions.
 *
 * Power Management Module — STM32C031C4T6 (LQFP-48, Cortex-M0+, 48 MHz HSI).
 */

#ifndef PMM_CONFIG_H
#define PMM_CONFIG_H

#include "stm32c0xx_hal.h"

/* ── I2C addresses (7-bit) ─────────────────────────────────────────────── */
#define BQ25895_I2C_ADDR        0x6BU
#define BQ27441_I2C_ADDR        0x55U

/* ── I2C bus ───────────────────────────────────────────────────────────── */
#define PMM_I2C                 I2C1
#define PMM_I2C_SCL_PORT        GPIOA
#define PMM_I2C_SCL_PIN         GPIO_PIN_9   /* PA9  — I2C1_SCL */
#define PMM_I2C_SDA_PORT        GPIOA
#define PMM_I2C_SDA_PIN         GPIO_PIN_10  /* PA10 — I2C1_SDA */
#define PMM_I2C_SPEED           400000U      /* 400 kHz fast-mode */

/* ── UART (debug) ─────────────────────────────────────────────────────── */
#define PMM_UART                USART2
#define PMM_UART_TX_PORT        GPIOA
#define PMM_UART_TX_PIN         GPIO_PIN_2   /* PA2 — USART2_TX */
#define PMM_UART_RX_PORT        GPIOA
#define PMM_UART_RX_PIN         GPIO_PIN_3   /* PA3 — USART2_RX */
#define PMM_UART_BAUD           115200U

/* ── ADC ───────────────────────────────────────────────────────────────── */
#define PMM_ADC                 ADC1
#define PMM_ADC_CH              ADC_CHANNEL_8   /* PA8 — ADC1_IN8 */
#define PMM_ADC_PORT            GPIOA
#define PMM_ADC_PIN             GPIO_PIN_8

/* ── GPIO outputs ──────────────────────────────────────────────────────── */
#define LOAD_SW_PORT            GPIOA
#define LOAD_SW_PIN             GPIO_PIN_0   /* PA0 — TPS22917 ON (active high) */

#define CHG_CE_PORT             GPIOA
#define CHG_CE_PIN              GPIO_PIN_4   /* PA4 — BQ25895 ~CE (active low) */

#define LED_PORT                GPIOA
#define LED_PIN                 GPIO_PIN_6   /* PA6 — D3 status LED (active high) */

#define PMM_INT_PORT            GPIOA
#define PMM_INT_PIN             GPIO_PIN_7   /* PA7 — PMM_INT (to host) */

#define SHDN_PORT               GPIOA
#define SHDN_PIN                GPIO_PIN_11  /* PA11 — SHDN control */

#define FORCE_ON_PORT           GPIOA
#define FORCE_ON_PIN            GPIO_PIN_12  /* PA12 — FORCE_ON control */

/* ── GPIO inputs ───────────────────────────────────────────────────────── */
#define BQ27441_INT_PORT        GPIOA
#define BQ27441_INT_PIN         GPIO_PIN_1   /* PA1 — BQ27441 GPOUT (active low) */

#define BQ25895_INT_PORT        GPIOA
#define BQ25895_INT_PIN         GPIO_PIN_5   /* PA5 — BQ25895 INT (active low) */

/* ── Clock configuration ───────────────────────────────────────────────── */
#define HSI_VALUE_HZ            48000000UL
#define SYSTEM_CLOCK_HZ         48000000UL

/* ── Timing constants (ms) ─────────────────────────────────────────────── */
#define LED_BLINK_PERIOD_MS     500U
#define POLL_INTERVAL_MS        1000U
#define STATUS_PRINT_MS         5000U
#define DEBOUNCE_MS             50U

/* ── Current sense resistor (10 mΩ) ───────────────────────────────────── */
#define SHUNT_RESISTANCE_MOHM   10U

#endif /* PMM_CONFIG_H */

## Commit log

2026-07-05 add simulations
    [PMM-1.0-R1.kicad_sch, WBBOMDesign1.csv, WBOperatingValuesDesign1.csv]
2026-07-07 3.3v regulator
    [PMM-1.0-R1.kicad_sch]
2026-07-09 fix aux 3.3v regulator
    [PMM-1.0-R1.kicad_sch, bq27441.kicad_sch, tps22917.kicad_sch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]
2026-07-09 add tlv 3.3v sheet
    [PMM-1.0-R1.kicad_sch, bq25895.kicad_sch, tlv75733.kicad_sch]
2026-07-09 update gitignore and whatnot
    [PMM-1.0-R1.kicad_sch, bq25895.kicad_sch, bq27441.kicad_sch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]
2026-07-14 finished schematics
    [PMM-1.0-R1.kicad_sch, bq25895.kicad_sch, bq27441.kicad_sch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]
2026-07-14 finished schematic and started pcb routing
    [PMM-1.0-R1.kicad_pcb, PMM-1.0-R1.kicad_sch, bq25895.kicad_sch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]
2026-07-14 more pcb routing
    [PMM-1.0-R1.kicad_pcb]
2026-07-14 start routing
    [PMM-1.0-R1.kicad_pcb, PMM-1.0-R1.kicad_sch, bq25895.kicad_sch]
2026-07-17 finished pcb
    [PMM-1.0-R1.kicad_pcb, PMM-1.0-R1.kicad_sch, bq25895.kicad_sch]
2026-07-17 add stuff
    [PMM-1.0-R1.kicad_pcb, PMM-1.0-R1.kicad_sch, bq25895.kicad_sch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]
2026-07-17 add silkscreen
    [PMM-1.0-R1.kicad_pcb, PMM-1.0-R1.kicad_sch, bq25895.kicad_sch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]
2026-07-21 add bom
    [BOM.csv]
2026-07-21 add 3D render and update README with images/BOM
